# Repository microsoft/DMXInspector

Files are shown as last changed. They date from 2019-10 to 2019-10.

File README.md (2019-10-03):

# DMX Inspector
The DMX Inspector is an Arduino-based device that will read out the data being sent on a DMX512 universe. This provides a developer of DMX control software and/or sequences with a desktop debugging display that confirms the data being sent to the lighting without having to actually be connected to a universe of DMX devices. It is a passive, read-only device.

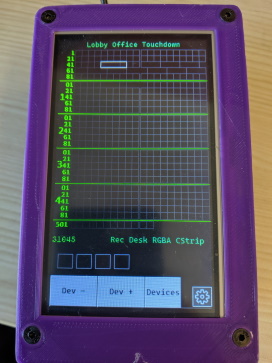
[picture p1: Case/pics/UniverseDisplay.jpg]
Universe display Universe Display
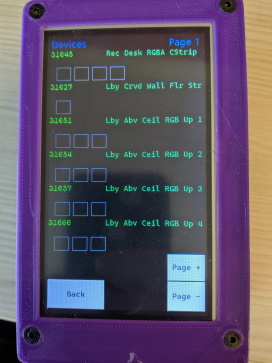
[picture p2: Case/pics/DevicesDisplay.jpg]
Devices display Devices Display
 

This project consists of several pieces:
* /Arduino: This is the project for the Arduino that does the actual work of listening to the DMX signal and driving the display. It relies on two libaries that must be installed to Arduino to communicate with the DMX hardware and the display:
  * Conceptinetics library as updated for this work: Clone from https://github.com/johnseghersmsft/Conceptinetics_RDM
  * Nextion libary as modified: https://github.com/johnseghersmsft/ITEADLIB_Arduino_Nextion
  Find detailed [build instructions at the Arduino/DmxInspector README](Arduino/DmxInspector/README.md)

* /Display: This is the Nextion code that powers the display. It uses a binary project file, `DmxDisplay.HMI` that can only be edited
  with [their editor, version 0.58](https://nextion.tech/). The DmxDisplay.tft file is the target file that can be loaded
  on a display by copying onto an SD card.
  * Insert the SD card into the display while powered off. 
  * Connect power and the bootloader will copy the file to the display.
  * Power down and remove the SD Card before powering back on.

* /Case: This contains the STL files for the case to hold the Arduino Mega, DMX Shield and Nextion display. I printed this in PLA using a 0.4mm nozzle at 0.15mm layer height without support. [See the README for more build details](Case/README.md)

# Contributing

This project welcomes contributions and suggestions.  Most contributions require you to agree to a
Contributor License Agreement (CLA) declaring that you have the right to, and actually do, grant us
the rights to use your contribution. For details, visit https://cla.opensource.microsoft.com.

When you submit a pull request, a CLA bot will automatically determine whether you need to provide
a CLA and decorate the PR appropriately (e.g., status check, comment). Simply follow the instructions
provided by the bot. You will only need to do this once across all repos using our CLA.

This project has adopted the [Microsoft Open Source Code of Conduct](https://opensource.microsoft.com/codeofconduct/).
For more information see the [Code of Conduct FAQ](https://opensource.microsoft.com/codeofconduct/faq/) or
contact [opencode@microsoft.com](mailto:opencode@microsoft.com) with any additional questions or comments.

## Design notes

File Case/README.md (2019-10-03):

# Building the DMX Inspector

The DMX Inspector consists of three off-the-shelf components and a small connector board with a 5V regulator.
* Arduino Mega 2650: The Mega is needed for additional COM ports and memory
  * Serial0 is reserved for USB connection to the PC for programming and debugging
  * Serial1 is used for reading the DMX signal
  * Serial2 is used for communicating with the Nextion display
  * Code compiles to 27630 bytes (10% of Mega's program space) and globals use 1684 bytes of RAM. Additionally there are some largish buffers that are dynamically allocated by libraries.
* DMX Shield made by Conceptinetics (CTC-DRA-10-R2 or similar). The shield is designed for either DMX Master or Slave functionality, but this build is specifically to function as a slave device.
* Nextion NX4827K043_011 display. This is a 4.3" TFT touch display, 480 x 272 pixels of Nextion's **Enhanced** series. While I am not using any instructions that are **Enhanced** only, I have only tested this on this specific model. Any different screen size will require changes to the Nextion HMI project.
* Breadboard wired with:
  * 5v regulator @ 500ma. I used a tiny inexpensive ($0.25) switching regulator that my local electronics store had picked up, but any regulator will work.
  * JP1 2-pin header to connect to the Arduino Serial2 port
  * JP2 4-pin header to connect to the Nextion Display

## Case
The case STL files provide a case to hold the boards securely and provide a nice bezel for the Nextion Display. I printed this in MatterHackers PLA on an Ultimaker 3 printer with 0.4mm nozzle and 0.15mm layers without support. The bezel is printed face down, the box bottom down. The spacers required are:
* 2x shortSpacer.stl: These are the standoffs for the breadboard. Any suitable spacer could be used here.
* 3x Spacer.stl: These hold the DMX Shield in place and are for the two end screw positions and the screw position by the power connector
* 1x SpacerWithCutout.stl: This spacer has a notch to clear the 2x3 header on the Arduino board near the hole.
This was about a 16 hour print.

## The Power and Distribution Breadboard
[Breadboard Schematic](pics/DMXInspectorSchematic.svg "Schematic of DMXInspector") 

The schematic shows the connections that need to be made. One could connect the Nextion display wires directly to the Arduino pins, but the Nextion connector cable comes with female header connectors. Also, having all four wires connecting to the same connector, and in the same order as the Nextion header made for a nicer build.

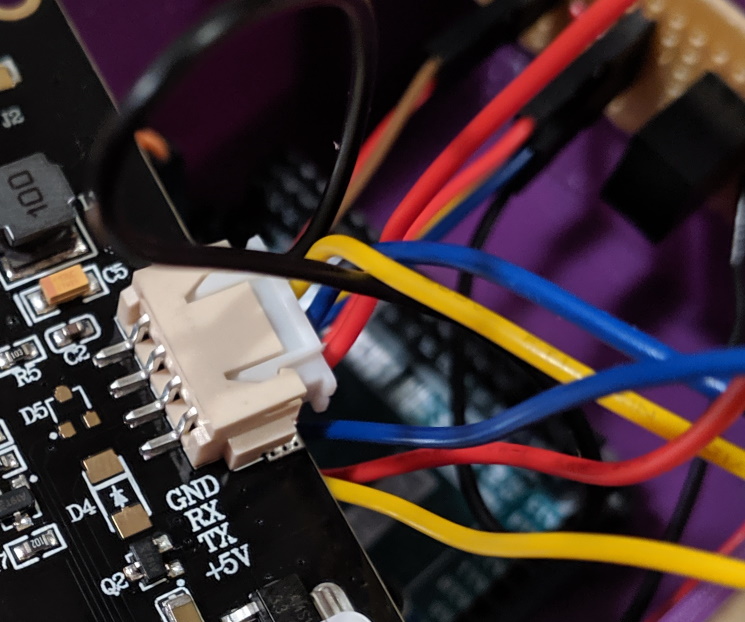
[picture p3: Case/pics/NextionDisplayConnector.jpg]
Nextion Connector Picture of Nextion Display connector

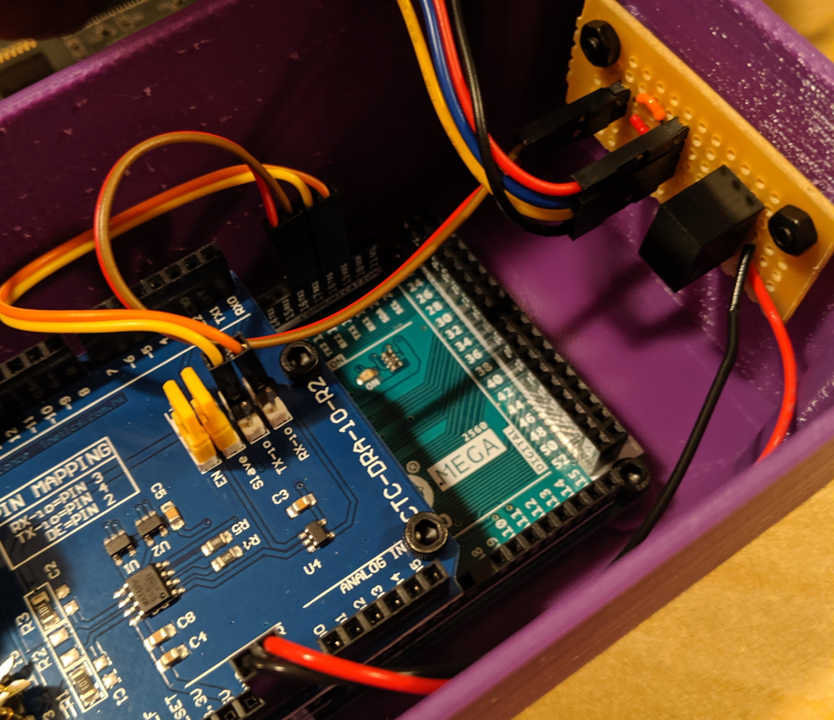
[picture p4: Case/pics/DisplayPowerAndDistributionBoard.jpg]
Breadboard Picture of breadboard and wiring


I built these on some old Radio Shack breadboards that had mounting holes 35.2mm (approx 1.4 inches) apart. It's probably easiest to mark your board to match the mounting holes and drill appropriate holes in the board.

NOTE: Be sure that the wires from the Arduino Serial2 port connect correctly to the breadboard so that the Arduino TX2 connects to the Nextion RX and the Arduino RX2 connects to the Nextion TX. Also be sure to have the correct polarity on the power connections.

NOTE: The Nextion display draws too much power to be supplied by the +5V regulator on the Arduino itself. One **might** be able to power the whole thing from USB without a regulator, but that would be pushing things.

## Assembling
At this point you've printed the case and assembled the breadboard. Now we'll put everything together.

### Preparing The Case
After printing the case, it is good to take a moment to get things prepared for assembly. You will want the following hardware:
* 4x 25mm M3 cap head screws: holds both the Arduino and DMX Shield firmly in place. These could be considered optional.
* 6x 8mm M3 cap head screws: 2 to hold the end of the Arduino in place, 4 to provide extra rigidity for the XLR connectors
* 2x 10mm M3 flat head screws: holds the breadboard in place
* 4x 16mm M3 flat head screws: holds the display and bezel in place
* 12x M3 hex nuts.

You will also need tools:
* 2.5mm hex screwdriver: all cap head screws
* 2mm hex strewdriver: all flat head screws
* A long (maybe 40mm) M3 screw. Yes, this is used as a tool.

#### Captive Nuts
Most of the nuts used in this build are held in place by hex depressions designed into the case. In my experience the hex holes are printed so that the nuts fit snuggly thus making it easy to pre-place them. All of these holes are printed on the bottom surface of the case, so (unless you used support) there will be a couple of loops where the hex turns into a circular hole. Just clean this loop out of each of the shallow holes (we'll get to the corners in a moment). Then seat the 6 nuts into the bottom of the case. Two ways to do this depending on how tight the holes are:
* Thread a nut onto the end of a screw and then press it into the hole. Once the nut is flush to the bottom of the case, unscrew the screw leaving the nut in the case.
* Put a screw (one of the 10mm should work) through the hole, without the boards in place. Thread a nut onto the screw and then tighten it to pull the nut into the hole. After it's set in place, remove the screw.

#### Corner Nuts
The corners are a bit of a special case. They are designed to use 16mm flathead screws, but the case is much more than 16mm high. So the hex holes run almost the height of the case. As you can see in the cross section most of the hex column is wider than the very top of it. This is so you can easily push a nut up in the column and then draw it tight and snug into the top 3mm.

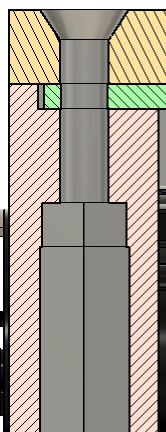
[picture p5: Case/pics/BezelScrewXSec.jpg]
cross section Cross section of corner screw mount


This is where that long M3 screw is used as a tool. You'll want to use two long-ish screws for this step, one of the 25mm screws will work well for the other one. 

First push the 25mm screw down through the hole at the top of the case (just the main case part--don't use the bezel here). This will push any filament loops from the transition from hex to circular hole out of the way. 

Next, thread a nut just on the end of the 40mm screw and push the nut up the hex column. It should hit the end of the 25mm screw. Now we're going to transfer the nut from the 40mm screw to the 25mm screw. Unscrew the 40mm screw a couple of turns. Then tighten the 25mm screw a couple of turns. This should allow it to grip the nut and you'll feel it bottom against the end of the long screw. Then unscrew the long screw and remove it.

Now tighten the short screw until snug. At this point the nut should be captive in the very end of the hex hole. Unscrew the 25mm screw being sure not to push the nut back out.

Do this for all four corner nuts.

### Remove support
There is a small piece of support modelled into the design between the holes for the two XLR connectors. There are "mouse bites" or perforations modelled into it to make it easy to remove. Just cut the support at the middle set of perforations and then break the pieces from the top and bottom perforations.

mouse bites Mouse bites in support 

### DMX Shield
The DMX Shield is designed to select between Serial0 (the only serial port on an UNO) or IO Pins through the use of jumpers. We are using a third option, connecting to Serial1. The center pin of the TX and RX pins on the shield connect to the RS485 chip. We'll connect those via jumper wires to the TX1 and RX1 connections on the Arduino Mega. Be sure to match TX to TX1 and RX to RX1. Also set the other two jumpers both to the left side as shown in this picture.

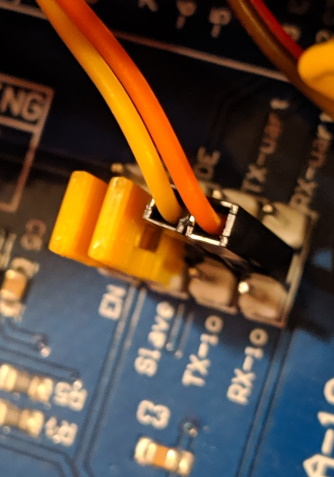
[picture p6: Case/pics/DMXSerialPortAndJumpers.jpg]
DMX Shield jumpers DMX Serial port connections and option jumpers
 

Carefully insert the DMX Shield into the headers of the Arduino Mega. They mount into the headers on the end closest to the power and USB connectors, using the same signals as present on the Arduino UNO. Then mount it in the case.

### Mounting the Arduino and DMX Shield
I found that fitting the board into place is easiest if you pre-position the 4 25mm screws through the DMX Shield, spacers, and Arduino but only flush with the bottom of the Arduino board. Once in place, you won't be able to reach the spacers near the front of the board unless you have tiny fingers or bent-nose pliers. 

Also, there is a pin from the power connector that is just in front of the hole on that side of the Arduino. I found that bending it over made an easier fit. Otherwise it hits the standoff for that screw.

Tilt the board so the spring button of the female XLR connector goes through the hole first, then line up the USB connector with its hole in the case. Things are a little snug, but once in place the USB will stick through the case by about 4mm and the power connector will be flush with the case. Both of the XLR connectors will be just a little past the case as well.

Now tighten the 25mm screws into the captive nuts. The screws should leave just a thread or so showing on the bottom nuts. Also, insert the two 10mm screws in the end of the Arduino board and tighten. You can also thread 8mm M3 screws into the XLR connectors (no nuts needed.)

Mount the breadboard on the back wall of the case and connect all of the wires.

### Wiring

| From | To | Notes |
| --- | --- | ----- |
| DMX Vin | 5V Vin | Power for the breadboard, and thus the display,<br> comes from Vin (sometimes labled Vraw) on the headers atop the DMX Shield.|
| DMX GND | 5V GND | And the ground connection |
| DMX TX | Arduino TX1 (18) | DMX Transmit pin (Not used by this tool, but if you want to repurpose for a controller, or RDM, this is needed) |
| DMX RX | Arduino RX1 (19) | DMX Receive pin |
| Arduino TX2 (16) | Breadboard JP1 TX2 | Connects to Display RX via breadboard connections. Sends data **to** the display. |
| Arduino RX2 (17) | Breadboard JP1 RX2 | Connects to Display TX via breadboard connections. Receives responses **from** the display. |
| Display +5V | Breadboard JP2 5V Vout | Regulated 5V to the display |
| Display TX | Breadboard JP2 TX | Sends data **from** the display |
| Display RX | Breadboard JP2 RX | Sends data **to** the display |
| Display GND | Breadboard JP2 GND | Ground connection to the display |

### Bezel
Lay the display on top of the corner supports. The case is a little longer than the display so there is room for the wires from the display connector to bend down. Thus the cable connection goes on the end toward the breadboard and the SD slot on the display faces the notch on the top of the case wall.

Set the bezel over the display. It should align properly with the screw holes and fit easily over the display. Mount in place with 4 16mm M3 flat head screws, tightening into the nuts you set in the earler step.

## Program the Display
* Load the file DmxDisplay.tft (in the /Display directory) onto the root of an empty SD card (FAT32 formatted, 32GB max).
* Put the SD card in the slot. The card contacts face UP. The slot is spring loaded, and when properly seated the SD card will be flush with the case.
* Connect power to the Arduino. The display will show the bootloader and the bootloader will load the firmware from the SD card. Wait until it displays its success message.
* Unplug the power.
* Remove the SD card (press in to click and release)
* Plug in the power. The display should show the empty grid with a label across the top "Updating Display..."

## Build the Arduino code
Full instructions for building the code are in the Arduino code README.

* Connect power
* Connect USB
* Upload code from the Arduino IDE (or VS Code)
* Connect to your DMX Universe.

## Defining Devices
The names and channel numbers for devices are clearly not going to be correct for your DMX universes. Therefore, you'll want to update the code to match your setup.

See the Arduino code README for details.

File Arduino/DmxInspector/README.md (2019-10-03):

# DMX Inspector
The DMX Inspector is an Arduino-based device that will read out the data being sent on a DMX512 universe. This provides a developer of DMX control software and/or the author of sequences with a desktop debugging display that confirms the data being sent to the lighting without having to actually be connected to a universe of DMX devices.

## Operation
The Inspector needs a 9v power adapter to operate. You should not attempt to power the device from USB--the Arduino may run, but the display is powered by a 5V regulator and the combination of the two devices may try to draw too much power from USB. One should  always plug in the power before connecting it to USB when making code changes. In normal operation, there is no need to connect the USB at all.

Use a 5-pin male DMX connector to 3-pin female XLR cable to connect the Inspector to the DMX universe. The DMX Shield has a termination resistor for terminating the line.

## Universe Display
When connected, the display will show all 512 values being sent by the DMX controller. For defined devices, the display will show RGB colors or levels of warm white, cool white, or amber. For all channels not defined, they will display as levels of grey (same as cool white).

Also, at the bottom of the screen a single device's information is shown. Pressing `Dev +` and `Dev -` buttons will sequence through the defined devices in channel order. A white box will highlight the channel(s) used by the device on the upper grid display.

## Devices Display
Pressing the `Devices` button changes to the Devices view where up to 6 devices are shown per page. Pressing `Page +` and `Page -` will cycle through pages of devices in the order defined in the Devices definitions tables.

The device displays--both on this page and on the Universe Display page--print the current numerical value of each channel above a box that displays the color or, in the case of generic devices, a linear representation of the value--like a slider filling the box proportionally to the value.

## Building the Code

Install Arduino v1.8.9 (1.8.10 has an annoying log spew during build when used with VS Code)
* I tend to install this at the root, (ex: c:\arduino)

Clone the DMX project to a directory of your choice from https://github.com/microsoft/DMXInspector:
```
git clone https://github.com/microsoft/DMXInspector.git
```

Install the two libraries. It is easiest to just clone them directly into the Arduino libraries cache in your home directory, `c:\users\<username>\Arduino\libraries`.
* DMX library from https://github.com/johnseghersmsft/Conceptinetics_RDM
```
git clone https://github.com/johnseghersmsft/Conceptinetics_RDM
```
* Nextion library https://github.com/johnseghersmsft/ITEADLIB_Arduino_Nextion
```
git clone https://github.com/johnseghersmsft/ITEADLIB_Arduino_Nextion
```
Then tell either the Arduino IDE or the VS Code IDE to include each library in the project. This will add a bunch of superfluous `#include` statements into DmxInspector.ino, so just remove them.

Suggestion: Setup VS Code to work as Arduino Editor
* Install the Arduino Extension: https://marketplace.visualstudio.com/items?itemName=vsciot-vscode.vscode-arduino
* Install the C/C++ Extension.
* In Edit->Preferences, In the Extensions section:
  * Set the Arduino: Path to the directory wherein you installed Arduino
  * Set the C_Cpp: IntelliSense Engine to "Tag Parser"
* Use `Show All Commands`--usually mapped to `F1` or `Ctrl-Shift-P` to bring up the command search. All Arduino commands are prefixed with "Arduino:"
  * Use `Arduino: Change Board Type` and select the Arduino Mega 2560
  * Use `Arduino: Select Serial Port` and choose the correct COM port
  * Use `Arduino: Change Baud Rate` to set 115200 if you're using the Serial Port Monitor in VS Code. I tend to use the Serial Monitor in the Arduino IDE (just have the IDE open to provide the button) because when you open that monitor it forces a reset on the Arduino. This allows you to get any debugging messages from the beginning.

## Defining Devices
The code contains the definitions for fixtures in the DMX Universe to be displayed. Of course, this needs to be configured for the actual universes with which you are working. This is accomplished by editing `DmxDeviceInfo.cpp`.

The devices present in a DMX universe are defined in tables such as this one. In the `DmxDeviceInfo.cpp` file there are six such universes defined.

``` C++
file DmxDeviceInfo.cpp:

const DmxDeviceInfo devices1[] PROGMEM
{
    //           123456789012345678901
    { "31045",  "Rec Desk RGBA CStrip",    DmxDeviceInfo::DeviceType::RGBA,           45 },
    { "31027",  "Lby Crvd Wall Flr Str",   DmxDeviceInfo::DeviceType::CW,             27 },
    { "31051",  "Lby Abv Ceil RGB Up 1",   DmxDeviceInfo::DeviceType::RGB,            51 },
    { "31054",  "Lby Abv Ceil RGB Up 2",   DmxDeviceInfo::DeviceType::RGB,            54 },
    { "31057",  "Lby Abv Ceil RGB Up 3",   DmxDeviceInfo::DeviceType::RGB,            57 },
    // ... More device definitions
    { "104099", "CC WallWash WW Flood",    DmxDeviceInfo::DeviceType::WW,             99 },
    { "104100", "CC WallWash CW Flood",    DmxDeviceInfo::DeviceType::CW,            100 },
    { "", "", DmxDeviceInfo::DeviceType::None, -1 }
};
```
I've abbreviated the table for clarity here. Each device, or fixture, is defined by one row of this array. The data within the braces initializes the four data members of the `DmxDeviceInfo` structure:
* Name: Up to 8 characters to be used as a short identifier
* Description: Up to 21 characters as a description of the device
* Type: The type of device. This defines the number of channels used by the device and how the channel data will be displayed.
* Channel: The DMX Channel number (1-based) of the first channel used by the device. For example, the first device is an LED light with Red, Green, Blue, and Amber on channels 45, 46, 47, and 48 respectively.

The devices can be listed in any order regardless of their channel numbers. The order listed is the order they will display on the Devices page. On the Universes page, they are sorted by channel number so the `Dev +` and `Dev -` buttons will scan through the devices in the order they appear on the grid.

Each of these array definitions must end with the Empty device: `{ "", "", DmxDeviceInfo::DeviceType::None, -1 }`. These are arrays of objects and the Empty device serves as an end marker in much the same way a `nullptr` acts as the end of an array of pointers.

## Defining Universes
The data in the current code defines devices for six DMX universes. The active universe can be selected from the settings page accessed by the gear icon on the Universe page.

The array of available universes is defined at the bottom of `DmxDeviceInfo.cpp`:
``` C++
file DmxDeviceInfo.cpp:

const DmxUniverse DmxUniverse::universes[] PROGMEM
{
    { 1, "Lobby Office Touchdown", devices1},
    { 2, "Plaza Cafe Makerspace", devices2},
    { 3, "Porch + Misc", devices3},
    { 4, "Family Room, Dining Room", devices4},
    { 5, "Kitchen", devices5},
    { 6, "Conversation Room", devices6}
};
```

This array defines the universes and links a description with the devices array for that universe. The universe description can be up to 29 characters long.

### Changing the Number of Universes
If you add or remove universes, you must update a constant, `kNumUniverses`, that informs the rest of the code of the number of universes:
``` C++
struct DmxUniverse
{
    static const int kNumUniverses = 6;
    static const int kMaxNameLength = 30;

    int number; 
    char desc[kMaxNameLength];
    DmxDeviceInfo * devices;

    static const DmxUniverse universes[kNumUniverses];
};
```

## Stored In Program Memory Address Space
These tables take up a lot of memory, and if they were defined in the normal data address space, they would quickly fill the available RAM. Thus, the use of the `PROGMEM` macro is required. This also means that reading this information requires special handling in the code, but we'll look at that later.

## Creating New Device Types
The `DeviceType` enum is defined in `DmxDeviceInfo.h` and can be extended to define new kinds of fixtures. Doing so requires several changes to be made.

### Defining the Number of Channels
The number of channels used for each kind of device is specified in the array `channelsForType`.

``` C++
file DmxDeviceInfo.cpp:

const uint8_t DmxDeviceInfo::channelsForType[] {0, 1, 1, 1, 1, 3, 4, 5, 4, 5, 4, 5, 6, 5, 6, 7, 8};
```
This has one entry per value of the `DeviceType` enum. Note that the Device display code can only show 8 channels of information, so if your new fixture uses more than 8 channels, you could break it up into multiple types and then enter multiple devices in the device table for that single fixture.

## Drawing On the Universe Page

Now that you've defined a new type and the number of channels it uses, you need to define how to draw it.

The grid display on the Universe page shows one color box per channel. Lights that use more than one channel to define a single color can draw that color across multiple boxes, merging them together. For example, the RGB type displays the combined color as a rectangle spanning three boxes.

This is handled by code in the method `DmxUniversePage::DrawDevice_P`. I've cut out a bunch of the cases for this document.
``` C++
file DmxUniversePage.cpp

int DmxUniversePage::DrawDevice_P(DmxDeviceInfo* pInfo)
{
    int chan = pInfo->GetChannel_P() - 1; // DMX channels are 1-based
    int channels = pInfo->GetNumChannels_P();

    uint8_t* pData = _data + chan;

// ... code to only update if there's a change in the data
    
    switch (pInfo->GetType_P())
    {
        case DmxDeviceInfo::DeviceType::None:
            chan++;
            break;
        case DmxDeviceInfo::DeviceType::Generic:
            chan = DisplayGrey(chan, *pData);
            break;
        case DmxDeviceInfo::DeviceType::WW:
            chan = DisplayWarmWhite(chan, *pData);
            break;
// ...
        case DmxDeviceInfo::DeviceType::RGB:
            chan = DisplayRGB(chan, pData);
            break;
// ...
        case DmxDeviceInfo::DeviceType::Gen8Chan:
            for (int i = 0; i < 8; i++)
                chan = DisplayGrey(chan, pData[i]);
            break;
    }
    memcpy(pLast, pData, channels);
    return chan - 1;        // return last channel actually drawn
}
```

There are a few things to note in this method. First, the `_P` suffix to the method. This indicates that it is expecting a pointer to Program Memory. The `pInfo` pointer is a pointer into the first 64K of the program address space, not a pointer to data space. Trying to use `pInfo->type` to get the device type won't work. The methods of the `DmxDeviceInfo` instead treat the `this` pointer appropriately, turning `pInfo->GetType_P()` into `pgm_read_byte(&this->type)`.

Next, this code reads the channel number and then immediately converts it from DMX's 1-based channels to a zero-based index suitable for use with pointers, and pData is computed to point to the data for the first channel of the device.

The `switch` decides how to draw the data. This uses various Display*Type* methods. We'll examine a couple of those in a moment. Each of these methods takes the `chan` value as an input for *where* to display the data and returns an updated `chan` value for where the *next* channel should be drawn. The `DrawDevice_P` method returns the chan value for the last channel actually drawn by this code (or in the case of `None` the channel skipped).

It should be noted that the `pData` pointer should not be changed during drawing since it is used at the end to record the channel data drawn in the buffer that is used for detecting changes. Communications with the Nextion Display makes updating the display an expensive operation, so the drawing code only updates the display for channels whose data has changed.

### Drawing Primatives
Drawing on the grid makes use of a single primative drawing method on the Nextion display. Each UI component defined on a page (of which there can only be 255 per page) has two event handlers. One is called when the user pushes on the component, the other when the user releases the touch. Nextion calls these Push and Pop. I call them Touch and Release.

The drawing code makes use of the ability to call these event handers directly via the `click` Nextion instruction. There are `NexHotspot` components on the pages to implement various drawing methods in their event handlers. The hotspots have no visual representation and the page's initialization event disables them from user touches.

### Implementing Draw Methods
``` C++
file DmxUniversePage.cpp:

int DmxUniversePage::DisplayRGB(int chan, const uint8_t* pData)
{
    DrawColor(chan, 3, RgbColorTo565(pData[0], pData[1], pData[2]));
    return chan + 3;
}

int DmxUniversePage::DisplayAmber(int chan, uint8_t value)
{
    DrawColor(chan, 1, ScaledRgbColorTo565(kRgbBaseAmber, value));
    return chan + 1;
}
void DmxUniversePage::DrawColor(uint16_t channelNumber, uint16_t span, uint16_t color)
{
    vxChan->setValue(channelNumber);
    vxNum->setValue(span);
    vxColor->setValue(color);
    SendClick(fnDrawColor, ClickTouch);
}
```
Here we see two of the drawing methods `DisplayRGB` and `DisplayAmber`. The each call `DrawColor` to communicate the draw command to the event handler of the `drawColor` Hotspot object on the Nextion display.

`DrawColor` works by setting the channel number and span to the Nextion variables `chan` and `num` and sets the 16-bit RGB565 color to the `color` Nextion variable. It then sends the Touch event to the `drawColor` Hotspot component.

The code in this event hander knows how to align the drawing to the correct channel box, and how to span multiple boxes, even when it will wrap to the next row.

### Color Handling
Colors on the Nextion display use RGB565 encoding, using the most significant 5 bits for 32 shades of red, the next 6 bits for 64 shades of green, and the least significant 5 bits for 32 shades of blue.

The colors defined by a three-channel RGB light, however, use 8-bits of data for each of the three colors. The `DisplayRGB` method uses a utility method, `RgbColorTo565` to convert these three values into a color the Nextion can display.

`DisplayAmber` needs to display the channel value as different brightnesses of a color. `ScaledRgbColorTo565` converts a 24-bit RGB value (in the low 3 bytes of a 32-bit int) into a 565 representation of the color after being multiplied by the channel value. A channel value of 255 equates to multiplying by 1.

### Multiple Draw Calls
More complex devices will span multiple boxes drawing different colors into multiple positions. Here we see two such:
``` C++
        case DmxDeviceInfo::DeviceType::RGBAC:
            chan = DisplayRGB(chan, pData);
            chan = DisplayAmber(chan, pData[3]);
            chan = DisplayCoolWhite(chan, pData[4]);
            break;
        // ...
        case DmxDeviceInfo::DeviceType::DRGBAC:
            chan = DisplayGrey(chan, *pData);
            chan = DisplayRGB(chan, pData + 1);
            chan = DisplayAmber(chan, pData[4]);
            chan = DisplayCoolWhite(chan, pData[5]);
            break;
```
These are for two device types. Both have RGB, Amber, and Cool White components, but the `DRGBAC` adds a dimmer at the start of the channels. Notice how the `DisplayRGB`, `DisplayAmber`, and `DisplayCoolWhite` methods are almost identical, with the data being passed shifted by one channel.

And alternative implementation might use the dimmer value to scale the RGB color and display that across the 4 channels.

Note that the `chan` variable is updated after each Display*Type* call and used in the next call. If this variable is not updated correctly some channels may be skipped (chan set too high), or the drawing loop may stall in an endless loop if the chan value is too low.

## Drawing On the Device Page
Drawing on the Devices Page (and also on the single device drawn on the bottom of the Universe Page) is handled by the `DmxDeviceSlot` and `DmxDeviceSlots` classes. The code is very similar to that of the Universe Page, but there are some additional options available.

Drawing the channel data consists of two parts, both implemented in `DmxDeviceSlot::DisplayData`. `DmxDeviceSlot` represents the display of a single device. Which device that is varies as you scroll through devices with the `Page +` and `Page -` buttons (`Dev +` and `Dev -` on the Universe Page).

### Channel Values As Text
The first part of the method creates a string consisting of the numeric values of each channel. These are aligned to display above the channel boxes.
``` C++
File DmxDeviceSlot.cpp:

oid DmxDeviceSlot::DisplayData(const uint8_t* data)
{
//...
    char buf[32];
    char* pValues = buf;
    uint8_t* pData = data + currentInfo->GetChannel_P() - 1;
    
    int numChannels = currentInfo->GetNumChannels_P();
//...
    uint16_t chan = currentInfo->GetChannel_P() - 1;
//...
    for (int i = 0; i < numChannels; i++)
    {
        uint8_t v = *pData++;

        if (i > 0)      // prepend with space if not first
            *pValues++ = ' ';

        uint8_t* pEnd = pValues + 3;
        if (v < 100)    // prepend with space for hundreds
            *pValues++ = ' ';

        if (v < 10)    // prepend with space for tens
            *pValues++ = ' ';

        itoa(v, pValues, 10);        
        pValues = pEnd;
    }
    txtDeviceChanValues->setText(buf);      // Set the text values for the data
```
The string formatted into `buf` will have up to 8 numbers, each taking a constant 3 characters each, and up to 7 spaces between them for a maximum length of 31 characters plus the null character at the end. It would be possible to extend this to take into account devices that combine two channels into 16-bit values. Just be sure the resultant string fits within the buffer. The text component on the Nextion display is expecting this size as well.

### Filling the Channel Boxes
The same fill options are available as on the Universe Page, with the addition of another: `DisplayLinear` that fills the box from the bottom up with white proportionately to the value of the channel.

Comparing one of the drawing primitives from Universe Page to that of a Device Slot illustrates the differences:
``` C++
File DmxUniversePage.cpp:

int DmxUniversePage::DisplayRGB(int chan, const uint8_t* pData)
{
    DrawColor(chan, 3, RgbColorTo565(pData[0], pData[1], pData[2]));
    return chan + 3;
}

File DmxDeviceSlot.cpp:
void DmxDeviceSlot::DisplayRGB(int chanSlot, const uint8_t* pData)
{
    pOwner->ChannelColor(slotId, 0, 3, DmxPageBase::RgbColorTo565(pData[0], pData[1], pData[2]));
}
```

As mentioned above, each slot knows what device it is drawing, and is told what position on the page it holds. This position is the `slotId` with which it is constructed. On the Devices Page, this ranges from 0-5. On the Universe Page there is only one slot with an id of 0.

The `ChannelColor` method is implemented in the `DmxDeviceSlots` class that contains the slots. `DmxDeviceSlots` in turn gets the Nextion Variables and Hotspots for implementing the drawing from the host pages. The drawing methods in the Nextion event handlers convert a slot number and channel number into the appropriate positions on their respective pages.

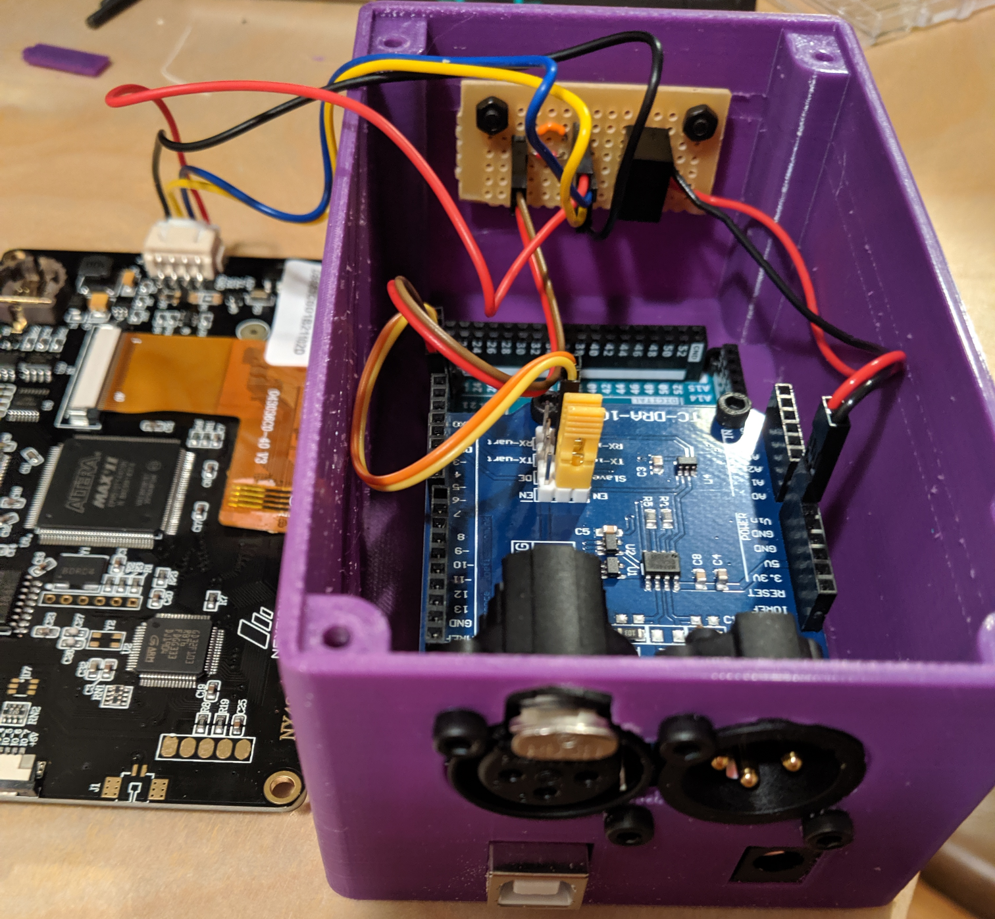
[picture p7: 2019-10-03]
Case/pics/FullCase.png

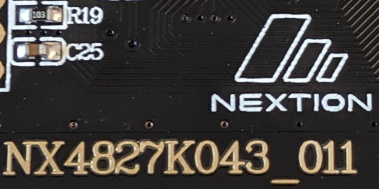
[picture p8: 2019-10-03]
Case/pics/NextionModelNumber.jpg

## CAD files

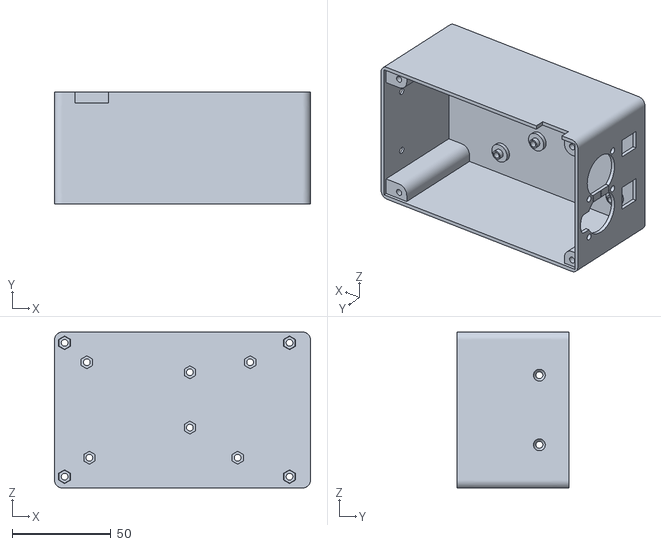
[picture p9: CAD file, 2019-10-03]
Case/Bottom.stl
129.4 x 56.5 x 78.8

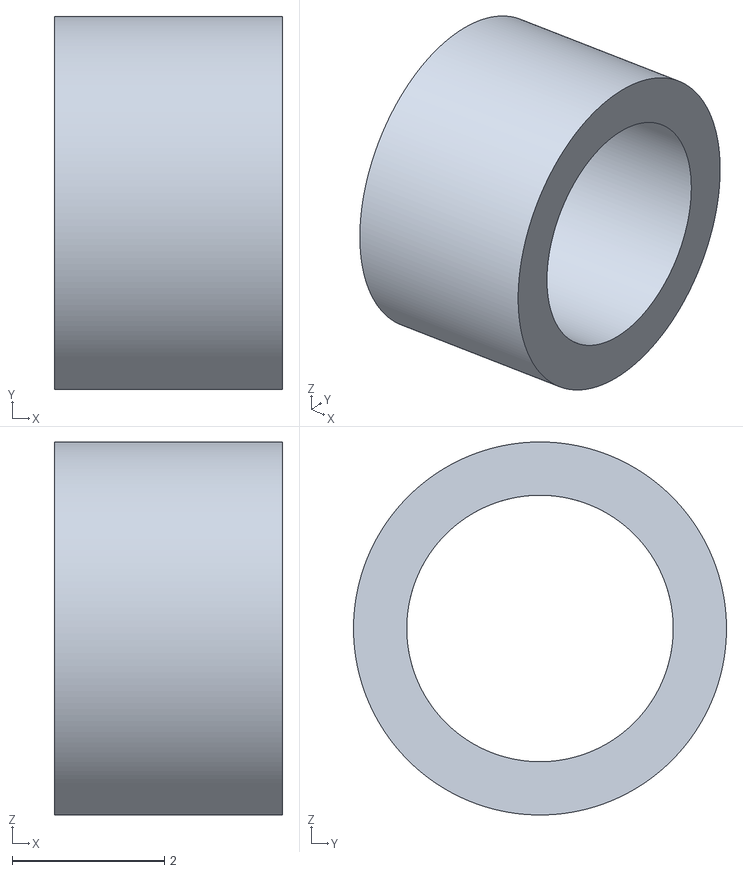
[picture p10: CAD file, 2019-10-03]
Case/shortSpacer.stl
3.00 x 4.90 x 4.90

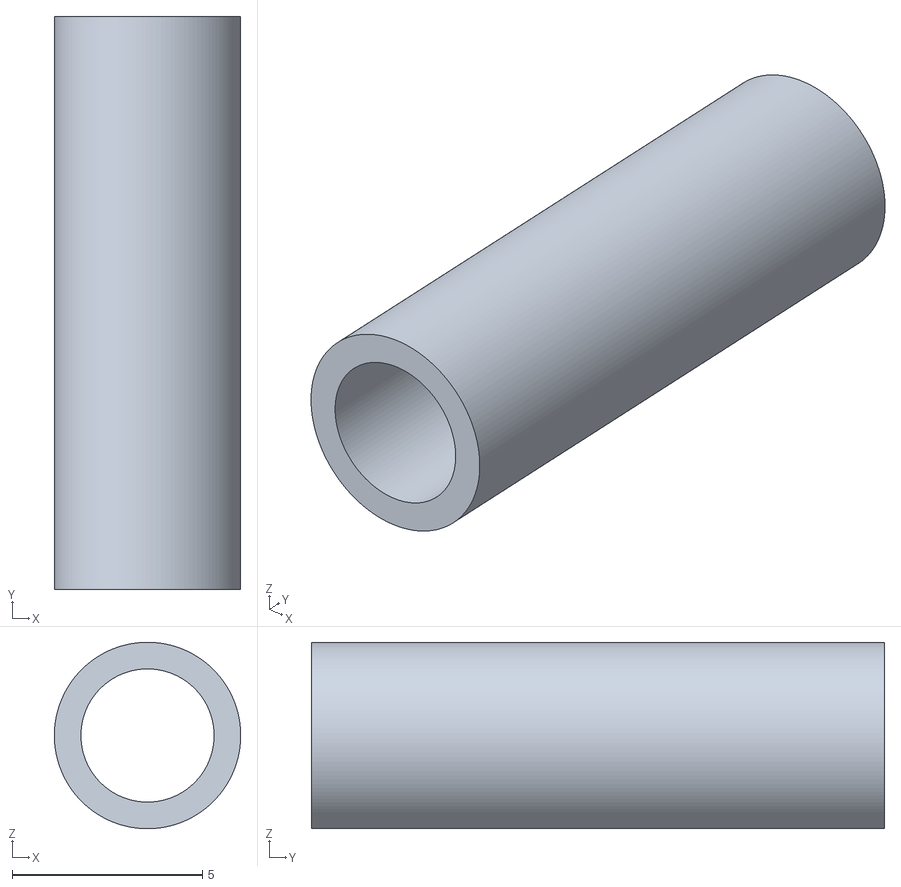
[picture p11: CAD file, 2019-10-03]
Case/Spacer.stl
4.90 x 15.1 x 4.90

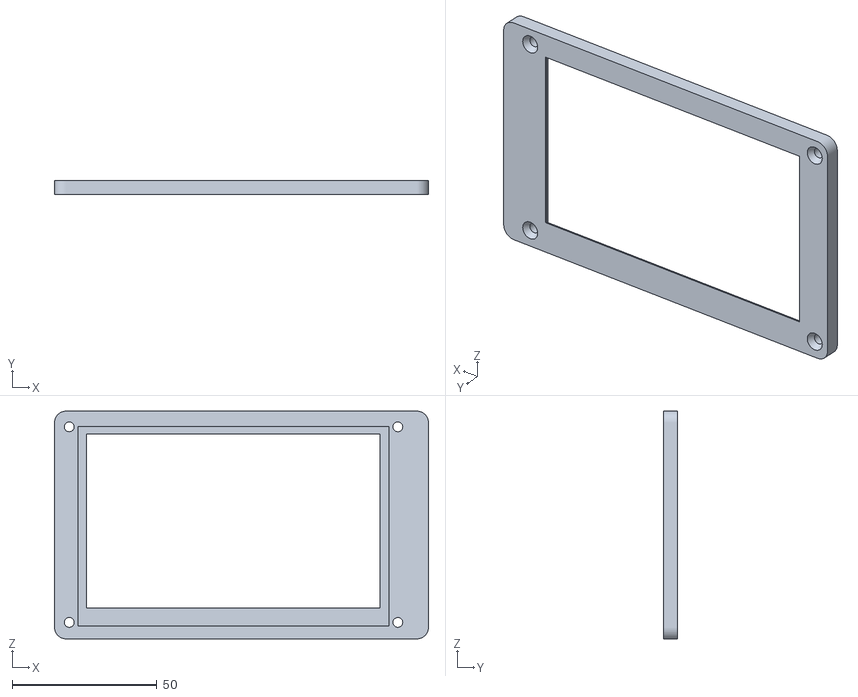
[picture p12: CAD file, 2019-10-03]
Case/Bezel.stl
129.4 x 5.00 x 78.8

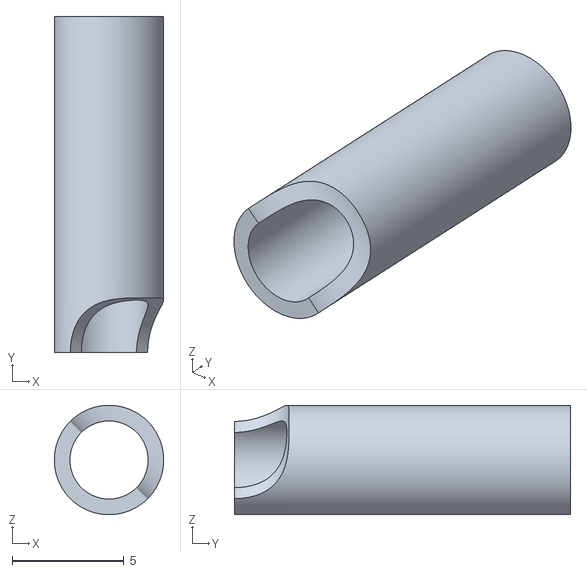
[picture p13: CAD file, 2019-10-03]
Case/SpacerWithCutout.stl
4.90 x 15.1 x 4.90

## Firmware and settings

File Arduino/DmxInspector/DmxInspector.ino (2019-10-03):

//*********************************************************
//
// Copyright (c) Microsoft Corporation.
// Licensed under the MIT License.
//
//*********************************************************
#include <Nextion.h>
#include <Conceptinetics.h>
#include "DmxPageBase.h"
#include "DmxUniversePage.h"
#include "DmxDevicesPage.h"
#include "DmxSettingsPage.h"



DmxUniversePage* Page0;
DmxDevicesPage* Page1;
DmxSettingsPage* Page2;
DMX_Slave* DmxReader;

uint32_t timeLastDataReceived;
uint16_t lastChannelsReceived;
uint32_t timeLastDataProcessed;
void setup() {
  // put your setup code here, to run once:
  Serial.begin(115200);

  timeLastDataReceived = 0;
  timeLastDataProcessed = 0;
  lastChannelsReceived = 0;

  uint32_t timer = millis();


  DmxReader = new DMX_Slave(512);
  DMX_FrameBuffer frameBuffer = DmxReader->getBuffer();
  if (frameBuffer.getBufferSize() != 513)
  {
    dbSerialPrintf_P("Buffer size %d is not expected 513\n", frameBuffer.getBufferSize());
  }
  uint8_t* channelData = frameBuffer.getBufferZeroAligned();

  //memset(channelData, 0xff, 512);   // Set all channels to max for a quick test
  
  Page0 = new DmxUniversePage(channelData);
  Page1 = new DmxDevicesPage(channelData);
  Page2 = new DmxSettingsPage();
  
  // NOTE: Nextion baud rate is set in the pre-initialization event of Page0 in
  // the Nextion editor. The rate there must match the rate set here.
  
  //nexInit(115200L, false);  // was getting occasional missed draw calls at this speed
  nexInit(57600L, false);
  DmxPageBase::SetCurrentPage(Page0);

  DmxReader->onReceiveComplete(&OnDmxReceiveComplete);
  DmxReader->enable();

}

void loop() {
  // put your main code here, to run repeatedly:
  nexLoop(DmxPageBase::CurrentPage->ListenList);
  DmxPageBase::CurrentPage->OnLoop();

  bool newData = timeLastDataReceived > timeLastDataProcessed;
  uint16_t count = lastChannelsReceived;
  uint32_t currentTime = millis();

  if (newData)
  {
    dbSerialPrintf_P("New data received %d channels %ld ms ago", count, currentTime - timeLastDataReceived);
    timeLastDataProcessed = currentTime;
  }
}

void OnDmxReceiveComplete(uint16_t channelsReceived)
{
  timeLastDataReceived = millis();
  lastChannelsReceived = channelsReceived;
}
